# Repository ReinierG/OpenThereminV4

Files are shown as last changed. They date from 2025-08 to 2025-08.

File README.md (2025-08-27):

# OpenThereminV4
Open Source Theremin Instrument

Schematics, printed circuit board (PCB) design, bill of materials (BOM) and Arduino UNO compatible software for the OpenTheremin V4

### Open Source Theremin based on the Arduino Platform

OpenTheremin is an arduino based real Therein instrument. The legendary music instrument was invented by Leon Theremin back in 1920. The theremin is played with two antennas, one to control the pitch and one for volume. The electronic shield with two ports to connect those antennas comprises two heterodyne oscillators to measure the distance of the hand to the antenna when playing the instrument. The resulting signal is fed into a AtMega328P microcontroller. After linearization and filtering the circuit generates the instruments sound that is then played through a high quality digital analog audio converter on the board. The characteristics of the sound can be determined by a wave table on the arduino.

For more info on the open source project and on availability of ready made shield see:

http://www.gaudi.ch/OpenTheremin/

Modifications to the original project
-  4-layer pcb for improved emc performance (slightly more expensive)
-  1 layer for ground, 1 layer for power (5V and a few 3.3V traces)
-  improved audio noise performance
-  added ESD protection (antennas, USB, audio connector, touch button)
-  added quite a few decoupling and bulk capacitors
-  solved a lot of design rule errors
-  removed some BOM errors and wrong footprints (3.5 mm audio connector)
-  100% software compatible
-  migrated to KiCAD 9.0.4

### Installation
1. Open up the Arduino IDE
2. Open the File "Open_Theremin_V4.ino"
3. Selecting the correct usb port on Tools -> Serial Port
4. Select the correct arduino board from Tools -> Board
5. Upload the code by clicking on the upload button.

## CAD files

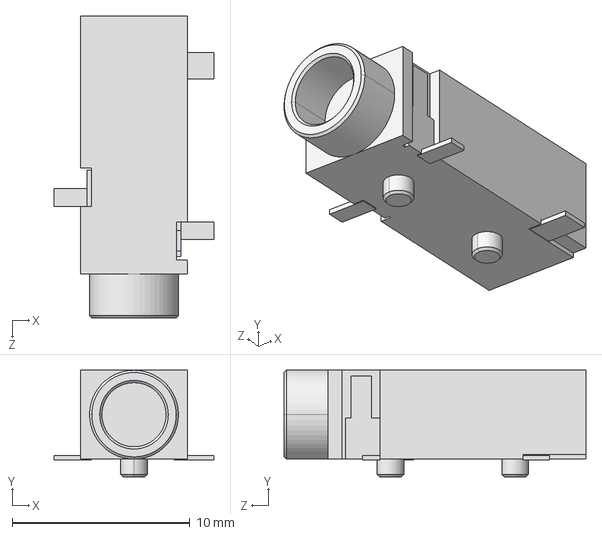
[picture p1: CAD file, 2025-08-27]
Electronics/35RASMT2BHNTRX.STEP
8.99 x 5.99 x 17.0 mm

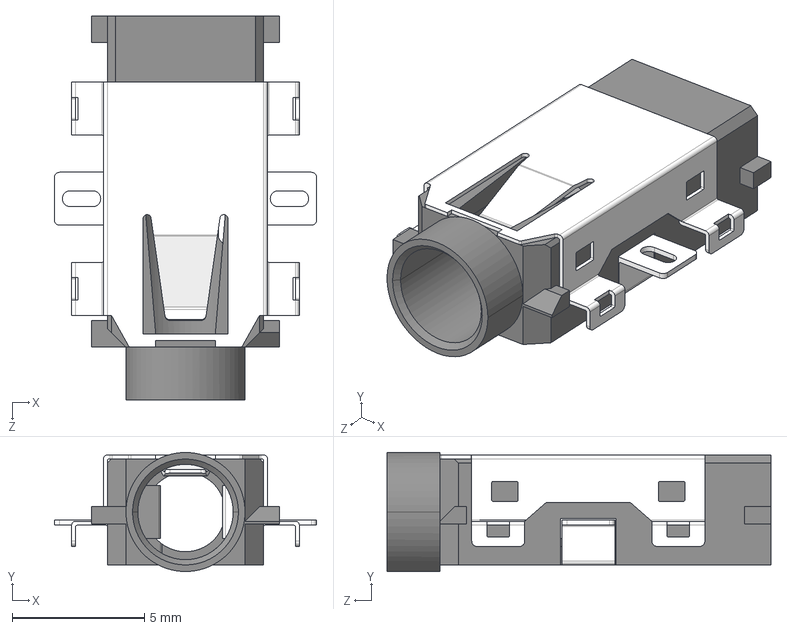
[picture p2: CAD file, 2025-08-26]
Electronics/Same_Sky_SJ-3502-SMT-TR.step
9.90 x 4.50 x 14.5 mm

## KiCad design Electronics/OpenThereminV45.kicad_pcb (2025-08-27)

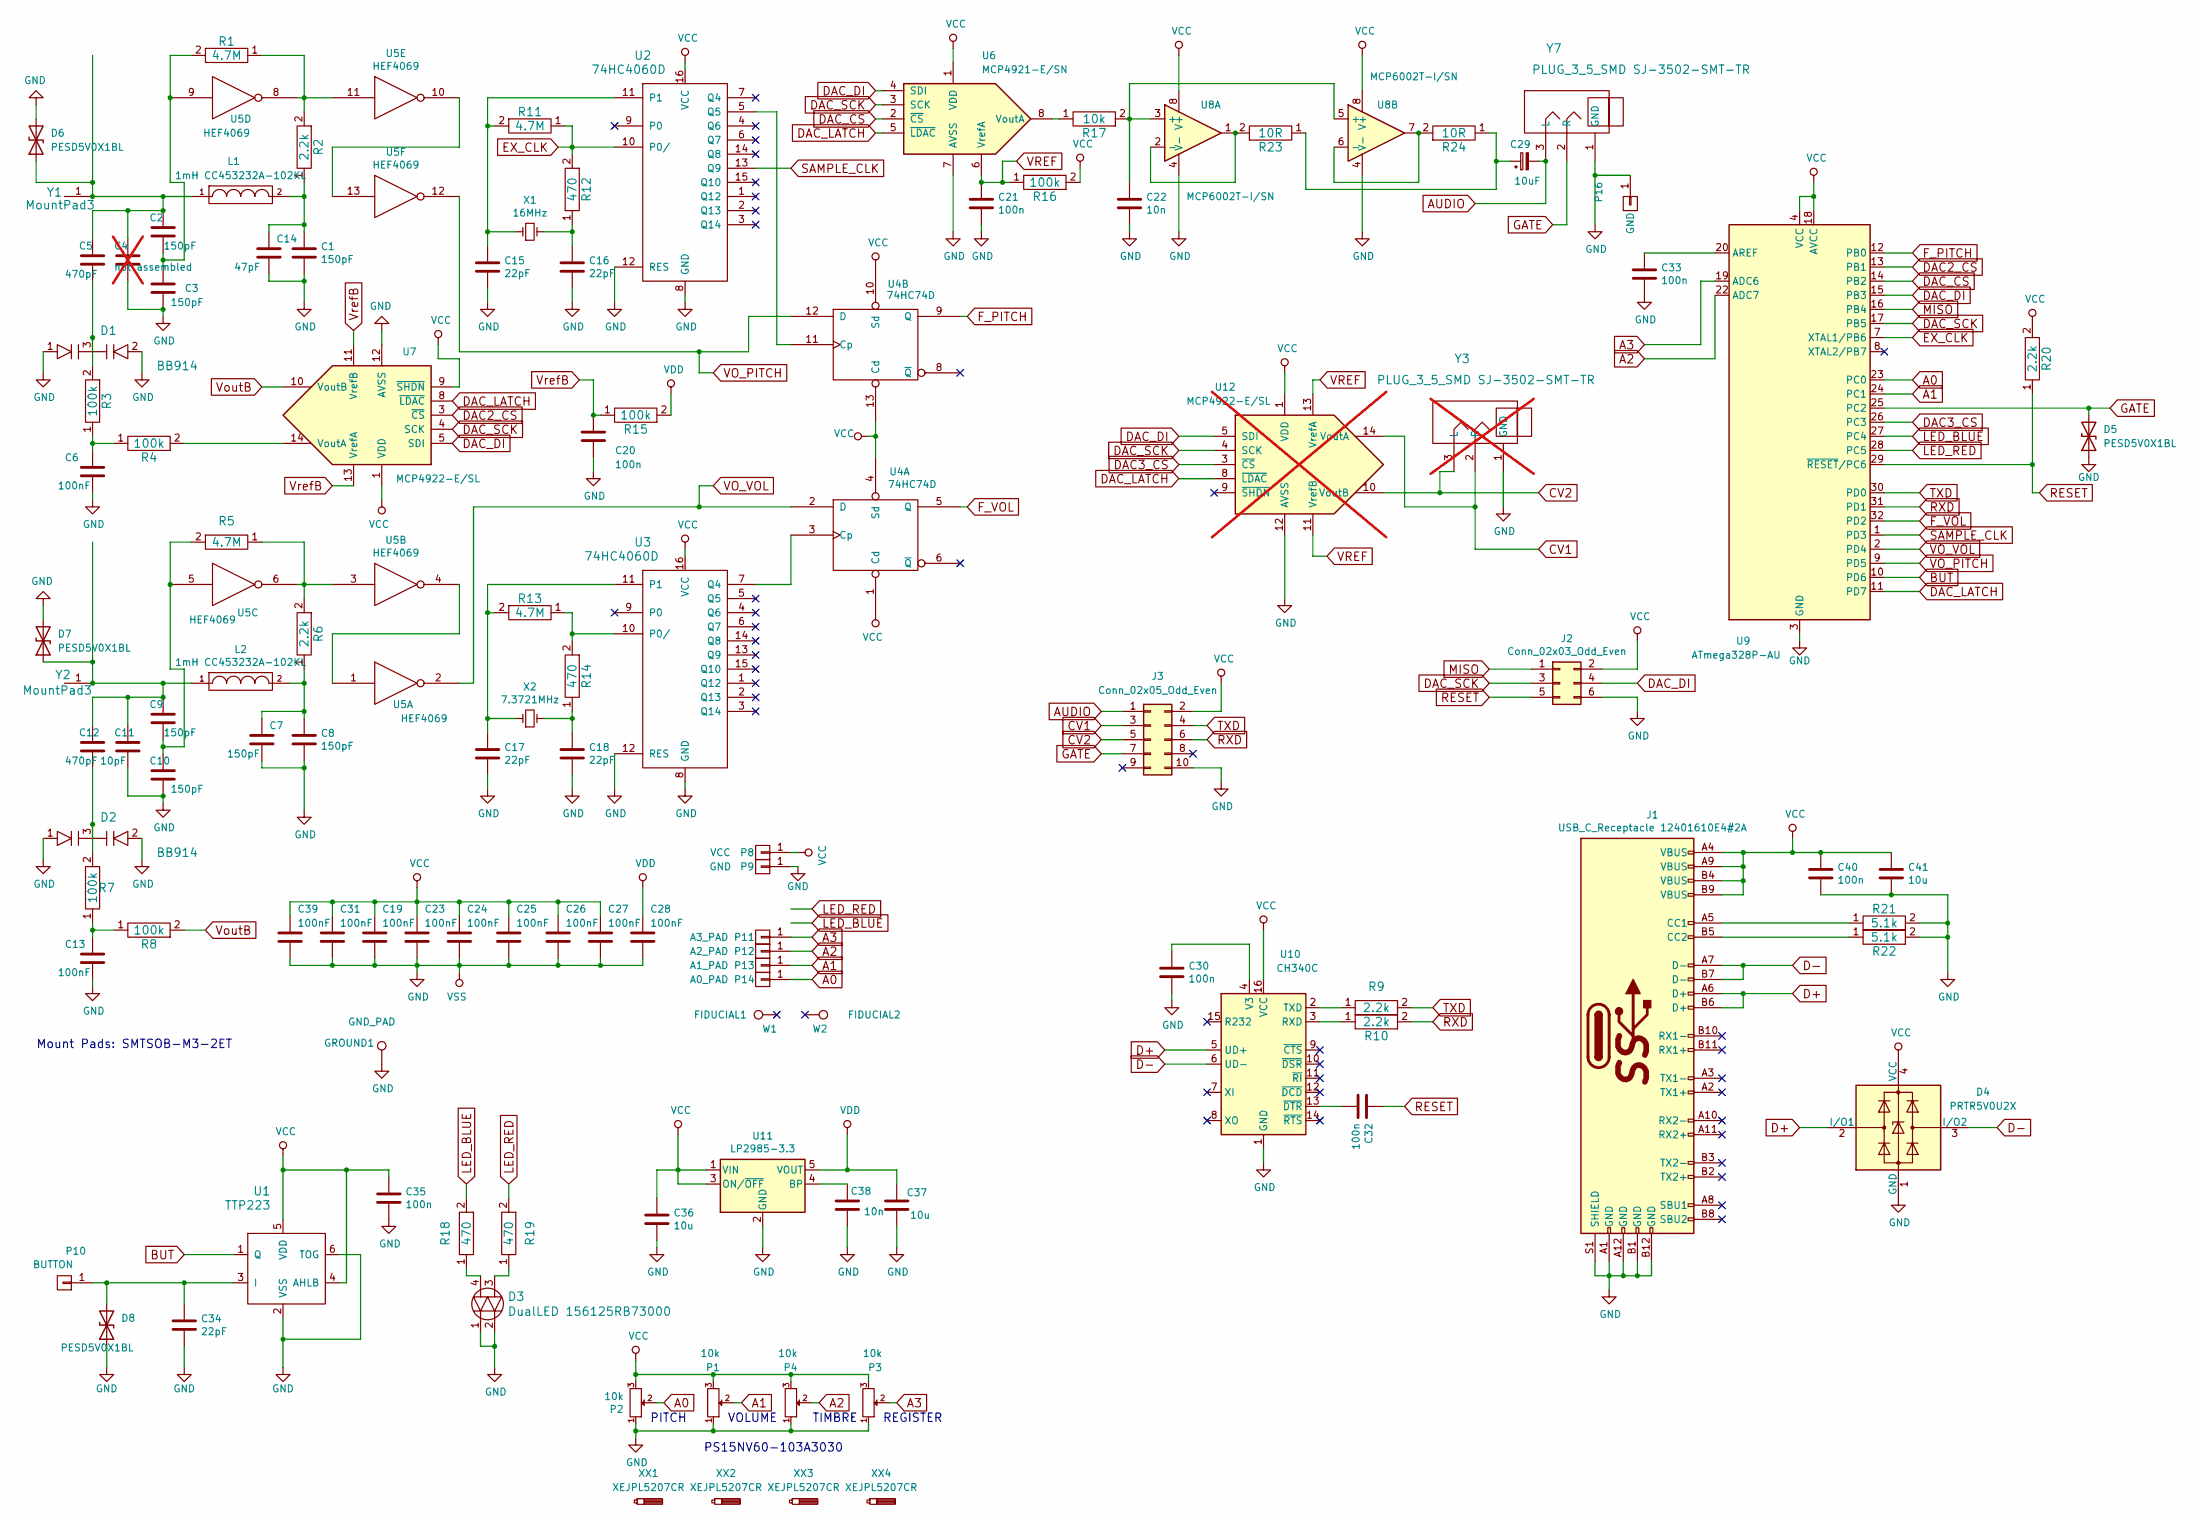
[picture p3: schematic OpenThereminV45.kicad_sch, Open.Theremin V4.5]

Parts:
C1, C2, C3, C7, C8, C9, C10: 150pF; C_0603_1608Metric
C4: not assembled; C_0603_1608Metric; not fitted
C5, C12: 470pF; C_0603_1608Metric
C6, C13, C19, C23, C24, C25, C26, C27, C28, C31, C39: 100nF; C_0603_1608Metric
C11: 10pF; C_0603_1608Metric
C14: 47pF; C_0603_1608Metric
C15, C16, C17, C18, C34: 22pF; C_0603_1608Metric
C20, C21, C30, C32, C33, C35, C40: 100n; C_0603_1608Metric
C22, C38: 10n; C_0603_1608Metric
C29: 10uF; C_0603_1608Metric
C36, C37, C41: 10u; C_0603_1608Metric
D1, D2: BB914; SOT-23
D3: DualLED 156125RB73000; WL-SBRW
D4: PRTR5V0U2X; SOT-143
D5, D6, D7, D8: PESD5V0X1BL; D_SOD-882
GROUND1: GND_PAD; GNDPad
J1: USB_C_Receptacle 12401610E4#2A; USB_C_Receptacle_Amphenol_12401610E4-2A
J2: Conn_02x03_Odd_Even; Tag-Connect_TC2030-IDC-NL_2x03_P1.27mm_Vertical
J3: Conn_02x05_Odd_Even; PinHeader_2x05_P1.27mm_Vertical_SMD
L1, L2: 1mH CC453232A-102KL; COIL_T
P1, P2, P3, P4: 10k; PS15NV60
P8: VCC; SMD_Pinheader_1_OT_BLANK
P9, P16: GND; SMD_Pinheader_1_OT_BLANK
P10: BUTTON; SensorButton
P11: A3_PAD; SMD_Pinheader_1_OT_BLANK
P12: A2_PAD; SMD_Pinheader_1_OT_BLANK
P13: A1_PAD; SMD_Pinheader_1_OT_BLANK
P14: A0_PAD; SMD_Pinheader_1_OT_BLANK
R1, R5, R11, R13: 4.7M; R_0603_1608Metric
R2, R6, R9, R10, R20: 2.2k; R_0603_1608Metric
R3, R4, R7, R8, R15, R16: 100k; R_0603_1608Metric
R12, R14, R18, R19: 470; R_0603_1608Metric
R17: 10k; R_0603_1608Metric
R21, R22: 5.1k; R_0603_1608Metric
R23, R24: 10R; R_0603_1608Metric
U1: TTP223; SOT-23-6
U2, U3: 74HC4060D; SOIC-16_3.9x9.9mm_P1.27mm
U4: 74HC74D; SOIC-14_3.9x8.7mm_P1.27mm
U5: HEF4069; SOIC-14_3.9x8.7mm_P1.27mm
U6: MCP4921-E/SN; SOIC-8_3.9x4.9mm_P1.27mm
U7: MCP4922-E/SL; SOIC-14_3.9x8.7mm_P1.27mm
U8: MCP6002T-I/SN; SOIC-8_3.9x4.9mm_P1.27mm
U9: ATmega328P-AU; TQFP-32_7x7mm_P0.8mm
U10: CH340C; SOIC-16_3.9x9.9mm_P1.27mm
U11: LP2985-3.3; SOT-23-5
U12: MCP4922-E/SL; SOIC-14_3.9x8.7mm_P1.27mm; not fitted
W1: FIDUCIAL1; Fiducial_1mm_Dia_2.54mm_Outer_CopperBottom
W2: FIDUCIAL2; Fiducial_1mm_Dia_2.54mm_Outer_CopperBottom
X1: 16MHz; Crystal_SMD_HC49-SD
X2: 7.3721MHz; Crystal_SMD_HC49-SD
XX1, XX2, XX3, XX4: XEJPL5207CR
Y1, Y2: MountPad3; SMTSOB_M3
Y3: PLUG_3_5_SMD SJ-3502-SMT-TR; SJ-3502-SMT-TR; not fitted
Y7: PLUG_3_5_SMD SJ-3502-SMT-TR; SJ-3502-SMT-TR

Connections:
A0: P2.2, P14.1, U9.23 (PC0)
A1: P1.2, P13.1, U9.24 (PC1)
A2: P4.2, P12.1, U9.22 (ADC7)
A3: P3.2, P11.1, U9.19 (ADC6)
AUDIO: C29.2, J3.1, Y7.3 (L)
BUT: U1.1 (Q), U9.10 (PD6)
CV1: J3.3, U12.14 (VoutA), Y3.2 (R)
CV2: J3.5, U12.10 (VoutB), Y3.3 (L)
D+: D4.2 (I/O1), J1.A6 (D+), J1.B6 (D+), U10.5 (UD+)
D-: D4.3 (I/O2), J1.A7 (D-), J1.B7 (D-), U10.6 (UD-)
DAC2_CS: U7.3 (~CS), U9.13 (PB1)
DAC3_CS: U9.26 (PC3), U12.3 (~CS)
DAC_CS: U6.2 (~CS), U9.14 (PB2)
DAC_DI: J2.4, U6.4 (SDI), U7.5 (SDI), U9.15 (PB3), U12.5 (SDI)
DAC_LATCH: U6.5 (~LDAC), U7.8 (~LDAC), U9.11 (PD7), U12.8 (~LDAC)
DAC_SCK: J2.3, U6.3 (SCK), U7.4 (SCK), U9.17 (PB5), U12.4 (SCK)
EX_CLK: R11.1, R12.2, U2.10 (P0/), U9.7 (XTAL1/PB6)
F_PITCH: U4.9 (Q), U9.12 (PB0)
F_VOL: U4.5 (Q), U9.32 (PD2)
GATE: D5.2 (A2), J3.7, U9.25 (PC2), Y7.2 (R)
GND: C1.2, C3.2, C4.2, C6.2, C7.2, C8.2, C10.2, C11.2, C13.2, C14.2, C15.2, C16.2, C17.2, C18.2, C19.2, C20.2, C21.2, C22.2, C23.2, C24.2, C25.2, C26.2, C27.2, C28.2, C30.2, C31.2, C33.2, C34.2, C35.2, C36.2, C37.2, C38.2, C39.2, C40.2, C41.2, D1.1, D1.2, D2.1, D2.2, D3.1, D3.2, D4.1 (GND), D5.1 (A1), D6.2 (A2), D7.2 (A2), D8.1 (A1), GROUND1.1, J1.A1 (GND), J1.A12 (GND), J1.B1 (GND), J1.B12 (GND), J1.S1 (SHIELD), J2.6, J3.10, P1.1, P2.1, P3.1, P4.1, P9.1, P16.1, R21.2, R22.2, U1.2 (VSS), U1.6 (TOG), U2.8 (GND), U2.12 (RES), U3.8 (GND), U3.12 (RES), U4.7 (GND), U5.7 (VSS), U6.7 (AVSS), U7.12 (AVSS), U8.4 (V-), U9.3 (GND), U9.5 (GND), U9.21 (GND), U10.1 (GND), U11.2 (GND), U12.12 (AVSS), Y3.1 (GND), Y7.1 (GND)
LED_BLUE: R18.2, U9.27 (PC4)
LED_RED: R19.2, U9.28 (PC5)
MISO: J2.1, U9.16 (PB4)
unnamed: C1.1, C14.1, L1.2, R2.1
unnamed: C2.2, C3.1, R1.2, U5.9
unnamed: C5.2, D1.3, R3.2
unnamed: C6.1, R3.1, R4.1
unnamed: C7.1, C8.1, L2.2, R6.1
unnamed: C9.2, C10.1, R5.2, U5.5
unnamed: C12.2, D2.3, R7.2
unnamed: C13.1, R7.1, R8.1
unnamed: C16.1, R12.1, X1.2
unnamed: C18.1, R14.1, X2.2
unnamed: C29.1, R23.1, R24.1
unnamed: D3.3, R19.1
unnamed: D3.4, R18.1
unnamed: C2.1, C4.1, C5.1, D6.1 (A1), L1.1, Y1.1
unnamed: C9.1, C11.1, C12.1, D7.1 (A1), L2.1, Y2.1
unnamed: C34.1, D8.2 (A2), P10.1, U1.3 (I)
unnamed: J1.A5 (CC1), R21.1
unnamed: J1.B5 (CC2), R22.1
unnamed: R1.1, R2.2, U5.8, U5.11
unnamed: R5.1, R6.2, U5.3, U5.6
unnamed: C15.1, R11.2, U2.11 (P1), X1.1
unnamed: U2.5 (Q5), U4.11 (Cp)
unnamed: R13.1, R14.2, U3.10 (P0/)
unnamed: C17.1, R13.2, U3.11 (P1), X2.1
unnamed: U3.7 (Q4), U4.3 (Cp)
unnamed: U5.1, U5.4
unnamed: U5.10, U5.13
unnamed: R17.1, U6.8 (VoutA)
unnamed: R4.2, U7.14 (VoutA)
unnamed: C22.1, R17.2, U8.3 (+), U8.5 (+)
unnamed: R23.2, U8.1, U8.2 (-)
unnamed: R24.2, U8.6 (-), U8.7
unnamed: C33.1, U9.20 (AREF)
unnamed: R10.1, U10.3 (RXD)
unnamed: R9.1, U10.2 (TXD)
unnamed: C30.1, U10.4 (V3)
unnamed: C32.2, U10.13 (~DTR)
unnamed: C38.1, U11.4 (BP)
RESET: C32.1, J2.5, R20.1, U9.29 (~RESET/PC6)
RXD: J3.6, R10.2, U9.31 (PD1)
SAMPLE_CLK: U2.13 (Q9), U9.1 (PD3)
TXD: J3.4, R9.2, U9.30 (PD0)
VCC: C19.1, C23.1, C24.1, C25.1, C26.1, C27.1, C31.1, C35.1, C36.1, C39.1, C40.1, C41.1, D4.4 (VCC), J1.A4 (VBUS), J1.A9 (VBUS), J1.B4 (VBUS), J1.B9 (VBUS), J2.2, J3.2, P1.3, P2.3, P3.3, P4.3, P8.1, R16.2, R20.2, U1.4 (AHLB), U1.5 (VDD), U2.16 (VCC), U3.16 (VCC), U4.1 (Cd), U4.4 (Sd), U4.10 (Sd), U4.13 (Cd), U4.14 (VCC), U6.1 (VDD), U7.1 (VDD), U7.9 (~SHDN), U8.8 (V+), U9.4 (VCC), U9.6 (VCC), U9.18 (AVCC), U10.16 (VCC), U11.1 (VIN), U11.3 (ON/~OFF), U12.1 (VDD)
VDD: C28.1, C37.1, R15.2, U5.14 (VDD), U11.5 (VOUT)
VO_PITCH: U4.12 (D), U5.12, U9.9 (PD5)
VO_VOL: U4.2 (D), U5.2, U9.2 (PD4)
VREF: C21.1, R16.1, U6.6 (VrefA), U12.11 (VrefB), U12.13 (VrefA)
VoutB: R8.2, U7.10 (VoutB)
VrefB: C20.1, R15.1, U7.11 (VrefB), U7.13 (VrefA)

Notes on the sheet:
REGISTER
VOLUME
TIMBRE
PITCH
PS15NV60-103A3030
Mount Pads: SMTSOB-M3-2ET

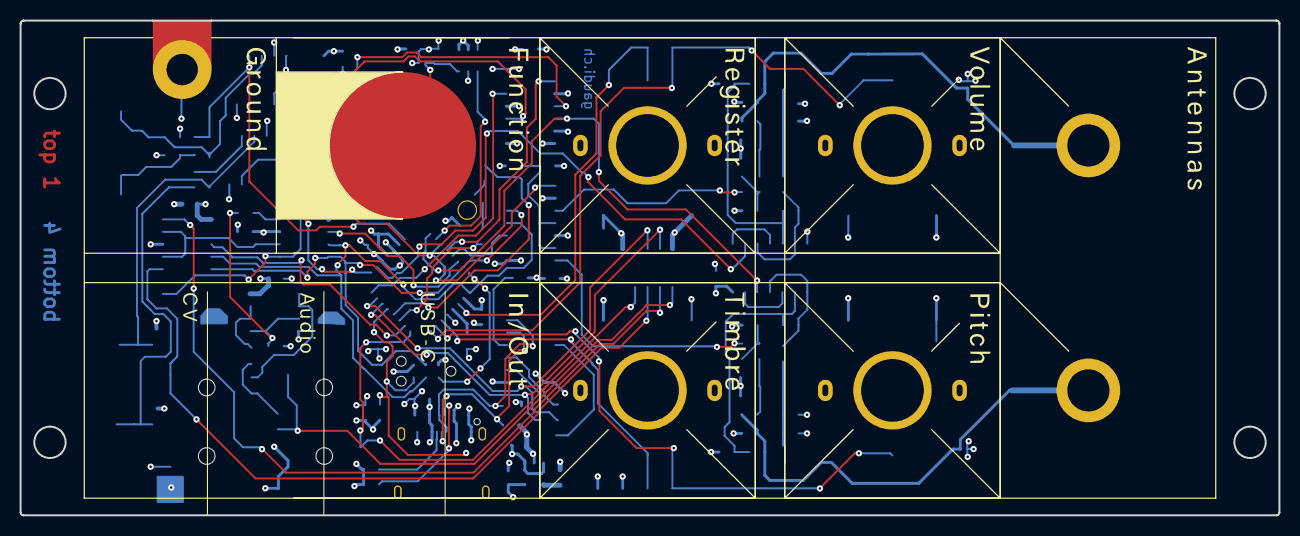
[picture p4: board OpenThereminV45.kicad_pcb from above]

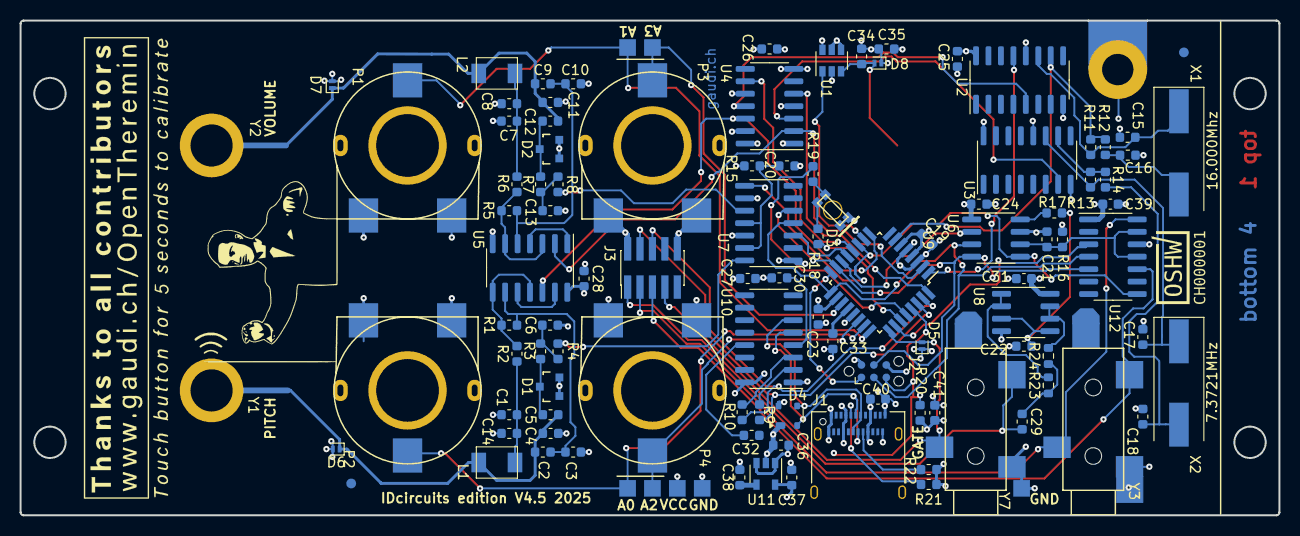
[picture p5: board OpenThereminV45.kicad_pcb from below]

Board: 4 copper layers, 128.5 x 50.5 mm, 111 parts (107 on the bottom side), 73 nets.

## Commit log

2025-08-26 changed to 4-layer and added esd protection and bypass caps
    not final yet, audio connector has wrong footprint
    [OpenThereminV45.kicad_pcb, OpenThereminV45.kicad_sch, Same_Sky_SJ-3502-SMT-TR.step]
2025-08-27 Added some text; moved some reference descriptors; pcb layer identification
    [35RASMT2BHNTRX.STEP, OpenThereminV45.kicad_pcb, OpenThereminV45.kicad_sch]
